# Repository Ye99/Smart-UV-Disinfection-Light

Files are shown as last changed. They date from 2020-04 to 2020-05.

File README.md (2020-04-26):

# Smart-UV-Disinfection-Light
Smart controller for UV disinfection light.

# Parts list:
* ESP8266 x 1. The "brain".
* RFP30N06LE x 1. Turn on/off the UV led.
* 2n7000 x 1. Logic shifter. Distance sensor runs on 5V; ESP8266 GPIO is only 
3.3V. This shifter converts it to 5V for the sensor Trigger signal.
* 22k and 11k resistor to convert 5V echo signal to 3.3v.
* LM317 x 1. For UV Led constant current source. Credits: Lewis Loflin
http://www.bristolwatch.com/ccs/LM317.htm
* 100 Ohm Potentiometer, to adjust constant current value. 

See main.py for wiring. TODO: add wiring diragram.

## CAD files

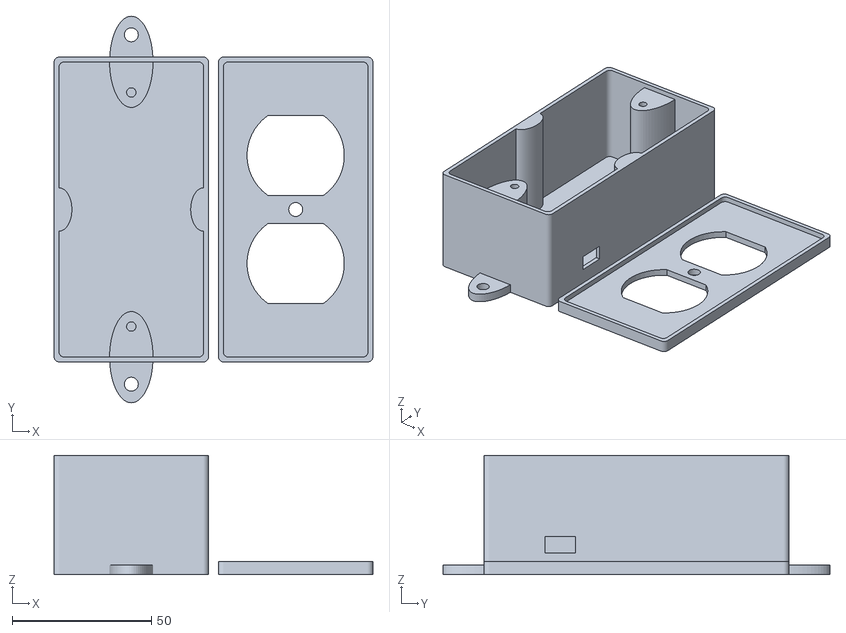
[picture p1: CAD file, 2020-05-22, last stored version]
ElectricalBox.stl
114.5 x 138.8 x 42.8

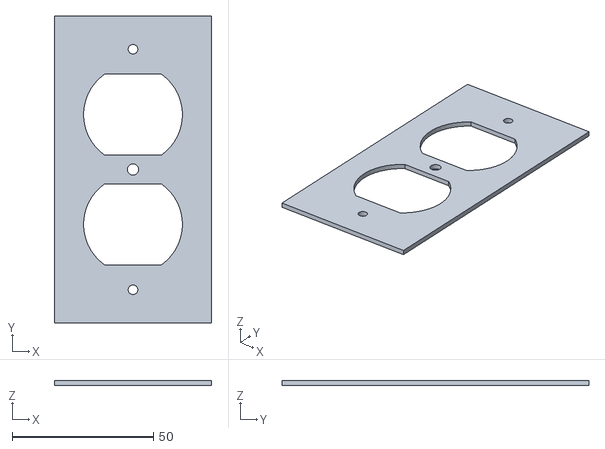
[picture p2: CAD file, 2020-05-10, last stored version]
ElectricalBox_top.stl
55.5 x 108.5 x 1.75

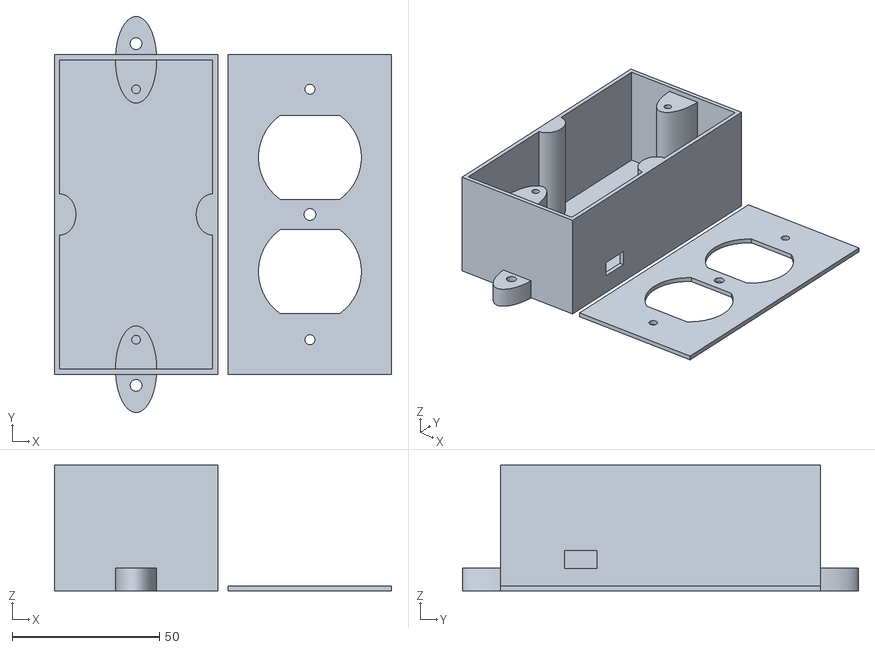
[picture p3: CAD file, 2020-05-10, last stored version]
ElectricalBox_bottom_and_top.stl
114.5 x 134.4 x 42.8

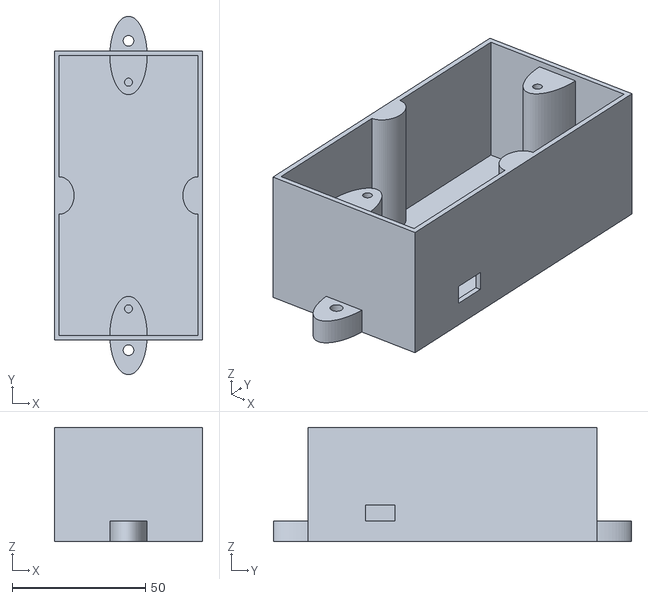
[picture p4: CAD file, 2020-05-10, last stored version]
ElectricalBox_bottom.stl
55.5 x 134.4 x 42.8

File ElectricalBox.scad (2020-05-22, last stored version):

/*
*  Created by: Anhtien Nguyen
*  Date:  June 11, 2018
*  Description:  an electrical box with the dimension
*/

/* By: Ye Zhang (mr.yezhang@gmail.com)
   Date: May 9, 2020
    Added screw tab out of box; removed box bottom screw holes, which are blocked after outlet is installed; Removed two supporting cylinders; Refactored code to imporve maintainability etc. 
   Date: May 10, 2020
    Remove two holes from cover.
    Enlarge screw holes.
    Fine tune screw hole distance. 
    Reduce box bottom tab thickness.
    Moved screw holes on bottom tab further from box wall. Give more work space. 
*/

use <roundedCube.scad>

// Choose, which part you want to see!
part = "all_parts__";  //[all_parts__:All Parts,bottom_part__:Bottom,top_part__:Top]

// Standard width is 69.33mm. This is inner space width.
width=52; //[51:85]
// Inner space height. Default 41mm
height=41;  // [37:70]

// Wall thickness in mm, add to width and height. Actuall wall (including cover) thickness is
// half of this value. 
wall_double_thickness=3.5; // [1:4]
// outlet screw diameter (mm) for the holes at 2 ends
outlet_screw_hole_diag=3.4; // [3:6]
// the screw hole on box bottom tab, to secure the box.
bottom_tab_screw_hole_diag=5;
// width of hole to run the input wires (mm)
// This 14/2 wire width is 10, height is 5
wires_hole_width=11; // [8:12]
// height of hole to run the input wires (mm)
wires_hole_height=6; // [4:12]
// https://smile.amazon.com/gp/product/B000BPEQCC/ref=ppx_yo_dt_b_search_asin_title?ie=UTF8&psc=1

// radius for rounded corner
rounded_corner_radius=2;

cover_alignment_tab_length=3;
cover_alignment_tab_height=4;
// the larger this value, the more cover free-play allowed.
cover_alignment_tab_tolerance=0.2;

// Program Section //
if(part == "bottom_part__") {
    box();
} else if(part == "top_part__") {
    cover();
} else if(part == "all_parts__") {
    all_parts();
} else {
    all_parts();
}

module all_parts() {
translate([0, 0, (height+wall_double_thickness/2)/2]) 
    box();

 // this put cover next to box
 // translate([width+(wall_double_thickness*2), 0, (wall_double_thickness/2+cover_wall_height)/2])
 // this displacement puts the cover on top
  translate([0,0,(height+wall_double_thickness/2)+1]) rotate([0, 180, 0])
    cover();
}

// Inner space length.
length=106; // Note: if you change this, you must update screw_posistion_from_edge and the value at "why is this magic number?" accordingly.
outlet_screw_hole_depth=35; // how far down is the outlet screw hole in supporting cylinder.
support_cylinder_radius=outlet_screw_hole_diag*2+1;

// distance between supporting cylinder and box top
cylinder_top_gap=5.5-wall_double_thickness; // deduct cover thickness so the outlet will be flush.

// outlet screw off set from edge. Change according to your measurement with caution!
// My desin references x,y,z 0 (center), and thus changing wall thickness won't inerference screw_position.
screw_posistion_from_edge=11; // Outlet screw holes are 84mm apart. Must be precise!

// cover wall height in mm, not including cover thickness.
cover_wall_height=3;

module one_plug_hole() {
    difference(){
        cylinder(r=17.4625, h=15, center = true, $fn=50);
        translate([-24.2875,-15,-cover_wall_height*2]) cube([10,37,15], center=false);
        translate([14.2875,-15,-cover_wall_height*2]) cube([10,37,15], center=false);
   }
}

module cover_alignment_tab() {
    cube([wall_double_thickness/2, cover_alignment_tab_length, cover_alignment_tab_height], center=false);
}

module cover(width=width, length=length, height=height, screw_pos=screw_posistion_from_edge) {
    union() {
        difference() {        
           difference() {
                // outside wall
                roundedCube([width + wall_double_thickness, length + wall_double_thickness, cover_wall_height+wall_double_thickness/2], center=true, r=rounded_corner_radius);
                // inside wall
                translate([0, 0, wall_double_thickness/2]) 
                    roundedCube([width, length, cover_wall_height], center=true, r=rounded_corner_radius);
            } 

            // Outlet opening and screw hole
            rotate([0,0,90]) 
                translate([-length/2+12, 0, 0]) // why is this magic number?
                    union() {
                        translate([height+19.3915, 0, 0]) 
                        {
                            one_plug_hole();
                        }
                    
                        translate([height-19.3915, 0, 0]){
                            one_plug_hole();
                        }
                        
                        // center hole. 4mm diameter.
                        // printed holes tend to shrink, give it 5mm. 
                        translate([height, 0, -3]) cylinder(r=2.5, h=20, $fn=50); 
                        translate([height, 0, 3.5]) cylinder(r1=2.5, r2=3.3, h=3);            
                    }
        }
        
        translate([-width/2+cover_alignment_tab_tolerance, length/3, 0]) 
            cover_alignment_tab();
        translate([-width/2+cover_alignment_tab_tolerance, -length/3, 0]) 
            cover_alignment_tab();
    }
}


module box_walls(ow_width, ow_length, ow_height) {
        difference() {
            // box walls
            difference() {
                // outside wall
                roundedCube([ow_width, ow_length, ow_height],center=true, r=rounded_corner_radius);
                // inside wall
                translate([0, 0, wall_double_thickness/2]) 
                    roundedCube([width, length, height], center=true, r=rounded_corner_radius);
            } 
        
           // input wires hole on side wall
           translate([ow_width/2, -(ow_length/4), -ow_height/4])
                // cube's x, y, z parameters confirm to the overall axes, making reasoning simple. 
                cube([wall_double_thickness*2, wires_hole_width, wires_hole_height], center=true);
    }
}

module outlet_screw_cylinder(length, ow_height, screw_pos) {
    cylinder_height = ow_height - cylinder_top_gap;

    translate([0, -length/2, -ow_height/2])
        difference(){
                // the support cylinder
                scale([1, 2.1, 1]) 
                    cylinder(h=cylinder_height, 
                            r1=support_cylinder_radius, 
                            r2=support_cylinder_radius, $fn=60, center=false);
                
                translate([0, -support_cylinder_radius*1.5, ow_height/2+wall_double_thickness]) // to make tab strong, its thickness equals to wall_double_thickness
                 {
                    scale([1, 1.5, 1])
                        // remove half of the outer cylinder                  
                        cube([support_cylinder_radius*2, support_cylinder_radius*2, 
                              ow_height], true);
                    // screw hole in the outside cylinder tab
                    translate([0, 2, -3])
                        cylinder(r=bottom_tab_screw_hole_diag/2, h=ow_height*2, $fn=50, center=true);
                }
                    
                // screw hole in the cylinder
                translate([0, screw_pos, cylinder_height-outlet_screw_hole_depth+1]) {
                        cylinder(r=outlet_screw_hole_diag/2, h=outlet_screw_hole_depth, $fn=50, center=false);
            }
        }
}

module lengh_support(ow_width, ow_height, wall_double_thickness) {
    rotate([0,0,90]) 
        translate([0, -(ow_width/2)+wall_double_thickness/2, -ow_height/2])
            scale([1, 0.6, 1]) // support_cylinder_radius shrink widthwise, leave more room for outlet body.
                difference(){
                    cylinder(ow_height, support_cylinder_radius, support_cylinder_radius, $fn=60);
                    translate([-support_cylinder_radius, -support_cylinder_radius*2-1, -1])
                        cube([support_cylinder_radius*2, support_cylinder_radius*2, ow_height+wall_double_thickness]);
                }
}

/*
 * Function box()
 * Draw the box 
 */
module box(width=width, length=length, height=height, screw_pos=screw_posistion_from_edge) {
    ow_width = width+wall_double_thickness;
    ow_length = length+wall_double_thickness;
    ow_height = height+wall_double_thickness/2;
   
    box_walls(ow_width, ow_length, ow_height);
      
    // outlet screw cylinder
    outlet_screw_cylinder(length, ow_height, screw_pos);
    // the other one
    rotate([0,0,180])  
        outlet_screw_cylinder(length, ow_height, screw_pos);
    
    // support lengh-wide
    lengh_support(ow_width, ow_height, wall_double_thickness);
    
    
    // the other support lengh-wide
    rotate([0,0,180]) 
        lengh_support(ow_width, ow_height, wall_double_thickness);
}

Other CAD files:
roundedCube.scad

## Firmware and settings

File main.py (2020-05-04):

from time import sleep_ms, ticks_ms, ticks_diff

from machine import Pin, ADC, reset
from micropython import const

from hcsr04 import HCSR04
from umqtt.simple import MQTTClient

_led_light_on_milliseconds = const(30000)
_led_light_current_to_voltage_resistor_value = const(47)

# Wiring:
# D7 UV light switch. High == on.
uv_light = Pin(13, Pin.OUT)


def turn_on_uv_light() -> None:
    uv_light.on()


def turn_off_uv_light() -> None:
    uv_light.off()


turn_off_uv_light()

# A0 UV light current (47 Ohm resister converts current to voltage) measurement.
uv_light_voltage = ADC(0)  # value 0, 1024 corresponding to 0. 3.3V


def map_adc_reading_to_voltage(value, left_min, left_max, right_min, right_max) -> float:
    # Figure out how 'wide' each range is
    left_span = left_max - left_min
    right_span = right_max - right_min

    # Convert the left range into a 0-1 range (float)
    value_scaled = float(value - left_min) / float(left_span)

    # Convert the 0-1 range into a value in the right range.
    return right_min + (value_scaled * right_span)


_ADC_reading_low_range = const(0)
_ADC__reading_high_range = const(1024)
_ADC_voltage_low_range = const(0)
_ADC_voltage_high_range = 3.3


def measure_uv_light_current() -> float:
    current_ma = map_adc_reading_to_voltage(uv_light_voltage.read(),
                                            _ADC_reading_low_range,
                                            _ADC__reading_high_range,
                                            _ADC_voltage_low_range,
                                            _ADC_voltage_high_range) / \
                 _led_light_current_to_voltage_resistor_value * 1000
    # print('UV light current is {} mA'.format(current_ma))
    return current_ma


_last_x_distance_values = []
_track_distance_value_number = const(8)


def compute_average(values_list) -> float:
    assert len(values_list) > 0, "doesn't make sense to compute empty list average"
    # print('values_list length is {}'.format(len(values_list)))
    if len(values_list) > 0:
        average = sum(values_list) / len(values_list)
        return average
    else:
        return 0


# Sometime the ultrasonic sensor returns readings much shorter than true value. Track the last x values and
# use their average to filter out such noise.
def update_distance_average(new_measure) -> float:
    if len(_last_x_distance_values) > _track_distance_value_number:
        _last_x_distance_values.pop(0)

    _last_x_distance_values.append(new_measure)
    return compute_average(_last_x_distance_values)


# Only call this method called when WiFi is connected.
# See https://docs.micropython.org/en/latest/esp8266/tutorial/network_basics.html#configuration-of-the-wifi
# ESP8266/32 persist WiFi configuration during power-off, and will reconnect automatically.
def publish_message(message) -> None:  # message is in binary format
    print('Publish message: {0}'.format(message))
    try:
        c = MQTTClient(client_id="smart_uv_light_umqtt_client",  # if username/pwd wrong, this will throw Exception
                       server="192.168.1.194",
                       user=b"mosquitto",
                       password=b"mosquitto",
                       ssl=False)
        if 0 == c.connect():  # 0 is success.
            c.publish(b"smart_uv_light_status_topic", message)
            c.disconnect()
        else:
            print('Connect to MQTT server failed. ')
    except OSError as exception:
        # When machine is just booted, WiFi hasn't been connected yet. Immediately invoke MQTT will throw error.
        # Instead of tracking startup grace period, just keep code simple by catching and log the error.
        print('publish_message encountered error {}'.format(exception))


last_reset_tick = ticks_ms()
_reset_interval_milliseconds = const(60 * 1000 * 30 )  # 30 minutes


def periodically_reset() -> None:
    tick_ms_elapsed = ticks_diff(ticks_ms(), last_reset_tick)
    # message = 'tick_ms elapsed {}'.format(tick_ms_elapsed)
    # publish_message(message)
    # print(message)

    if tick_ms_elapsed > _reset_interval_milliseconds:
        # free is in boot so it's available to REPL, for convenience. Import it to make this dependency explicit?
        publish_message('Reset. Current memory usage is {}'.format(free()))  # Also works as heartbeat.
        sleep_ms(2000)
        reset()
        #  Don't need to record last_reset_tick here. Because after reset, code will do it.


# ESP32 Devkit print Dxx, the xx is pin number used below.
# ESP8266 map Dxx to GPIO number https://randomnerdtutorials.com/esp8266-pinout-reference-gpios/
# D5 Trigger (reversed logic, low -> high because of the MOSFET driver in front of distance sensor.
# HCSR04 library needs to be modified)
# D6 Echo
sensor = HCSR04(trigger_pin=14, echo_pin=12)

start_ticks = 0

_loop_sleep_ms = const(6)
_led_on_distance_cm = const(73)  # 29 inch

# For testing average function.
# import urandom

while True:
    try:
        distance_reading = sensor.distance_cm()
        # distance_reading = urandom.getrandbits(8)
        # print('The last distance reading is {} cm.'.format(distance_reading))
        if distance_reading <= 2:
            # It can give negative readings. Hardware bug or library bug?
            # print('Drop value below the Ultrasonic lower range.')
            continue

        average_distance = update_distance_average(distance_reading)
        # print('Current average distance is {} cm.'.format(average_distance))

        if average_distance < _led_on_distance_cm and uv_light.value() == 0:
            start_ticks = ticks_ms()
            turn_on_uv_light()
            publish_message('Turn light on. Average distance {}. '
                            'Light current is {} mA. '.format(average_distance, measure_uv_light_current()))
        if 1 == uv_light.value() and ticks_diff(ticks_ms(), start_ticks) > _led_light_on_milliseconds:
            # publish_message('Before turning light off. Current is {} mA.'.format(measure_uv_light_current()))
            turn_off_uv_light()
            publish_message('Light is off. Current is {} mA.'.format(measure_uv_light_current()))

        measure_uv_light_current()
        periodically_reset()
        sleep_ms(_loop_sleep_ms)
    except OSError as ex:
        error_message = 'ERROR: {}'.format(ex)
        # If function, invoked from here, raises exception, the loop can terminate.
        publish_message(error_message)
        print(error_message)

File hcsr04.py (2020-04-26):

# Notice this library use inversed logic level, to work with N-Channel MOSFET driver in front of the distance sensor.
import machine, time
from machine import Pin
from micropython import const

__version__ = '0.1.0'
__author__ = 'Roberto Sánchez'
__license__ = "Apache License 2.0. https://www.apache.org/licenses/LICENSE-2.0"

_default_echo_timeout_us = const(30000)

class HCSR04:
    """
    Driver to use the untrasonic sensor HC-SR04.
    The sensor range is between 2cm and 4m.

    The timeouts received listening to echo pin are converted to OSError('Out of range')

    """
    # Timeout is based in chip range limit (400cm)
    # TIMEOUT_US = 500*2*30
    def __init__(self, trigger_pin, echo_pin, echo_timeout_us=_default_echo_timeout_us):
        """
        trigger_pin: Output pin to send pulses
        echo_pin: Readonly pin to measure the distance. The pin should be protected with 1k resistor
        echo_timeout_us: Timeout in microseconds to listen to echo pin.
        By default is based in sensor limit range (4m)
        """
        self.echo_timeout_us = echo_timeout_us
        # Init trigger pin (out)
        self.trigger = Pin(trigger_pin, mode=Pin.OUT, pull=None)
        self.trigger.on()

        # Init echo pin (in)
        self.echo = Pin(echo_pin, mode=Pin.IN, pull=None)

    def _send_pulse_and_wait(self):
        """
        Send the pulse to trigger and listen on echo pin.
        We use the method `machine.time_pulse_us()` to get the microseconds until the echo is received.
        """
        self.trigger.on() # Stabilize the sensor
        time.sleep_us(5)
        self.trigger.off()
        # Send a 10us pulse.
        time.sleep_us(10)
        self.trigger.on()
        try:
            pulse_time = machine.time_pulse_us(self.echo, 1, self.echo_timeout_us)
            return pulse_time
        except OSError as ex:
            if ex.args[0] == 110: # 110 = ETIMEDOUT
                raise OSError('Out of range')
            raise ex

    def distance_mm(self):
        """
        Get the distance in milimeters without floating point operations.
        """
        pulse_time = self._send_pulse_and_wait()

        # To calculate the distance we get the pulse_time and divide it by 2
        # (the pulse walk the distance twice) and by 29.1 because
        # the sound speed on air (343.2 m/s), that It's equivalent to
        # 0.34320 mm/us that is 1mm each 2.91us
        # pulse_time // 2 // 2.91 -> pulse_time // 5.82 -> pulse_time * 100 // 582
        mm = pulse_time * 100 // 582
        return mm

    def distance_cm(self):
        """
        Get the distance in centimeters with floating point operations.
        It returns a float
        """
        pulse_time = self._send_pulse_and_wait()

        # To calculate the distance we get the pulse_time and divide it by 2
        # (the pulse walk the distance twice) and by 29.1 becasue
        # the sound speed on air (343.2 m/s), that It's equivalent to
        # 0.034320 cm/us that is 1cm each 29.1us
        cms = (pulse_time / 2) / 29.1
        return cms

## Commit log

2020-04-26 Turn on UV for 30 seconds, when there is object within 40 cm of distance sensor. Also monitors UV current. Added Readme.
2020-05-03 Use average of the past several distance readings to filter out noise.
    [main.py]
2020-05-03 Move 8266 Pin comment closer to where it's used.
2020-05-03 Fix bug forgot to import MQTTClient; don't turn off light if it's off already.
    [main.py]
2020-05-03 Tune sampling interval to minimize distance measuring noise. Send metrics through MQTT.
    [main.py]
2020-05-03 Fix styling according to PEP08. Fix spelling typos. Add dependency "machine".
    [main.py]
2020-05-04 Publish error to MQTT; periodically reset.
    [main.py]
2020-05-04 Send memory free telemetry through MQTT before reset; Catch publish_message to make it more robust.
    [main.py]
2020-05-10 Add electrical box 3D model
    [ElectricalBox.scad, ElectricalBox_bottom.stl, ElectricalBox_bottom_and_top.stl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]
2020-05-11 Remove two holes from cover. Enlarge screw holes. Fine tune screw hole distance. Reduce box bottom tab thickness. Moved screw holes on bottom tab further from box wall. Give more work space.
    [ElectricalBox.scad, ElectricalBox.stl, ElectricalBox_bottom.stl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]
2020-05-11 Refactor named constant to be more readable. Remove spaces around '='.
    [ElectricalBox.scad, ElectricalBox.stl]
2020-05-12 Add 1mm to box length.
    [ElectricalBox.scad]
2020-05-12 Add wall to cover, just like commercial outlet cover does.
    [ElectricalBox.scad]
2020-05-12 Make box round-corner, using robert@cosmicrealms.com from https://github.com/Sembiance/openscad-modules; fix bug box cover doesn't touch build surface.
    [ElectricalBox.scad, roundedCube.scad]
2020-05-22 add cover alignment tabs
    [ElectricalBox.scad, ElectricalBox.stl]
